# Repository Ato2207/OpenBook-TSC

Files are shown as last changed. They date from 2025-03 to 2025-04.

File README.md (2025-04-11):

# OpenBook-TSC

# 1. Diagrama bloc
Block Diagram OpenBook

# 2. Bill Of Materials (BOM)
| Nr. | Componentă | Cantitate | Link achiziție | Datasheet |
|----|---|---|---|---|
| 1  | ESP32-C6-WROOM-1-N8 | 1 | [Mouser](https://ro.mouser.com/ProductDetail/Espressif-Systems/ESP32-C6-WROOM-1-N8?qs=8Wlm6%252BaMh8ST02Gmwp74cw%3D%3D) | [Datasheet](https://ro.mouser.com/datasheet/2/891/Espressif_ESP32_C6_WROOM_1__Datasheet_V0_1_PRELIMI-3239987.pdf) |
| 2  | Regulator de tensiune 3.3V  | 1 | [Mouser](https://www.mouser.co.uk/ProductDetail/Torex-Semiconductor/XC6220A331MR-G?qs=AsjdqWjXhJ8ZSWznL1J0gg%3D%3D) | [Datasheet](https://www.mouser.co.uk/datasheet/2/760/xc6220-3371556.pdf) |
| 3  | Display | 1 | https://www.waveshare.com/7.5inch-e-paper-hat.htm | [Datasheet](https://files.waveshare.com/upload/6/60/7.5inch_e-Paper_V2_Specification.pdf) |
| 4  | Senzor BME688 | 1 | [Mouser](https://ro.mouser.com/ProductDetail/Bosch-Sensortec/BME688?qs=IS%252B4QmGtzzqQoVDscqwx3A%3D%3D)| [Datasheet](https://ro.mouser.com/datasheet/2/783/bst_bme688_fl000-2307034.pdf) |
| 5  | Baterie | 1 | [Mouser](https://www.tme.eu/ro/details/accu-lp584174_cl/acumulatori/cellevia-batteries/l584174/)| [Datasheet](https://www.tme.eu/Document/e0683d8c34e6d878124489f71bffb6ee/cel0014.pdf) |
| 6  | Fuel Gauge | 1 | [Mouser](https://ro.mouser.com/ProductDetail/Analog-Devices-Maxim-Integrated/MAX17048G%2bT10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) | [Datasheet](https://ro.mouser.com/datasheet/2/609/MAX17048_MAX17049-3469099.pdf) |
| 7  | Controller de incarcare | 1 | [Mouser](https://ro.mouser.com/ProductDetail/Microchip-Technology/MCP73831T-2ACI-MC?qs=yUQqVecv4quJ3ICqm%2FGZxw%3D%3D)| [Datasheet](https://ro.mouser.com/datasheet/2/268/MCP73831_Family_Data_Sheet_DS20001984H-3441711.pdf) |
| 8  | Butoane  | 3 | [Mouser](https://ro.mouser.com/ProductDetail/Panasonic/EVQ-Q2S03W?qs=WwqriLBepZso3gwmd6qd3A%3D%3D) | [Datasheet](https://4donline.ihs.com/images/VipMasterIC/IC/PANA/PANA-S-A0000770395/PANA-S-A0000770395-1.pdf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) |
| 9  | Conector USB-C  | 1 | [Mouser](https://ro.mouser.com/ProductDetail/Amphenol-Commercial-Products/12401598E42A?qs=367PjNmvCmllVMBVyIyS3w%3D%3D) | [Datasheet](https://cdn.amphenol-cs.com/media/wysiwyg/files/documentation/datasheet/inputoutput/io_usb_type_c.pdf) |
| 10  | Conector card SD  | 1 | [Mouser](https://www.digikey.ro/en/products/detail/attend-technology/112A-TAAR-R03/17633923) | [Datasheet](https://www.attend.com.tw/data/download/file/112A-TAAR-R03_Spec.pdf) |
| 11  | RTC DS3231  | 1 | [Mouser](https://www.optimusdigital.ro/en/others/12402-ds3231-real-time-clock-module.html) | [Datasheet](https://www.analog.com/media/en/technical-documentation/data-sheets/ds3231.pdf) |
| 12  | Memorie Flash 64MB externa  | 1 | [Mouser](https://ro.mouser.com/ProductDetail/Winbond/W25Q512JVEIQ?qs=l7cgNqFNU1jw6svr3at6tA%3D%3D) | [Datasheet](https://ro.mouser.com/datasheet/2/949/Winbond_W25Q512JV_Datasheet-3240039.pdf) |
| 13 | Tranzistoare  | 3 | - | - |
| 14 | Diode | 10 | - | - |
| 15 | Condensatori diversi  | 28 | - | - |
| 16  | Rezistente diverse | 24  | -  | - |

# 3. Functionalitate Hardware
  ## 3.1 Componente
  - **ESP32-C6-WROOM-1-N8** – Microcontroler principal care gestionează comunicațiile (SPI, I2C, UART) și controlează perifericele.  
  - **Conector USB-C & Protecție ESD** – Permite alimentarea prin USB-C și protejează circuitul de descărcările electrostatice.  
  - **Controler de Încărcare MCP73831** – Reglează încărcarea bateriei Li-Po și gestionează curentul de alimentare.  
  - **Baterie Li-Po** – Asigură alimentarea de rezervă pentru funcționare independentă de sursa USB.  
  - **Regulator de Tensiune LDO** – Stabilizează alimentarea la 3.3V pentru microcontroler și componente auxiliare.  
  - **Memorie Flash NOR Externă (64MB)** – Stocare suplimentară pentru date.
  - **Modul RTC DS3231SN** – Oferă funcționalitate de ceas în timp real, suportând alarme și detectarea pierderii tensiunii..  
  - **Senzor Ambiental BME688** – Măsoară temperatura, umiditatea, presiunea și calitatea aerului. Comunicare prin I2C, cu suport pentru conectare rapidă (Qwiic/Stemma QT).  
  - **E-Paper Display Drive Circuit si Header** – Genereaza semnalele necesare pentru controlul ecranului E-Paper.
  - **Slot SD Card** – Permite stocarea locală a datelor și fișierelor de configurare. 
  - **Supervizor de Tensiune + Butoane Reset/Boot** – Monitorizează alimentarea și asigură resetarea sistemului atunci când este necesar.

  ## 3.2 Specificatii de comunicare
  - **I2C** – Utilizat pentru senzorul BME688 și modulul DS3231SN.
  - **SPI** – Folosit pentru NOR Flash, display-ul E-Paper și cardul SD.
  - **UART** – Disponibil pentru debugging sau conectarea altor module. 
  - **Wi-Fi & Bluetooth LE** – Furnizate de ESP32-C6 pentru conectivitate wireless.

# 4. Pini ESP32-C6-WROOM-1-N8 si utilizare
| Pin ESP32-C6| Funcție | Modul de utilizare |
|---|---|---|
| **3V3** | Supply | Furnizează tensiune de 3.3V pentru componente. |
| **GND** | Ground | Referință pentru circuit. |
| **EN** | Enable | Permite pornirea/resetarea modulului (tensiune ridicată = activ). |
| **IO0** | Interrupt | Pentru notificari, conectat la modulul RTC. |
| **IO1** | RTC CLK | Semnal de ceas pentru modulul RTC. |
| **IO2** | SPI MISO | Primire date de la periferice conectate prin SPI. |
| **IO3** | Status | Semnalizeaza starea de ocupay a display-ului. |
| **IO4** | Slave Select | Selecteaza cardul SD. |
| **IO5** | Data/Command | Selecteaza intre modul de date si comenzi. |
| **IO6** | SPI CLK | Semnal de ceas pentru SPI. |
| **IO7** | SPI MOSI | Transfer date catre periferice conectate prin SPI. |
| **IO8** | GPIO | Pin general GPIO. |
| **IO9** | Boot | Conectat la un buton pentru intrarea in modul de boot. |
| **IO10** | Chip Select | Activeaza comunicarea cu display-ul. |
| **IO11** | Chip Select | Activeaza comunicarea cu memoria flash. | 
| **IO12** | USB_D- | Pentru USB. |
| **IO13** | USB_D+ | Pentru USB. |
| **IO15** | Change | Conectat la un buton. |
| **IO16** | TX | Pentru UART. |
| **IO17** | RX | Pentru UART. |
| **IO18** | RTC_RST | Pentru resetarea modulului RTC. |
| **IO19** | I2C_PW | Supply pentru I2C. |
| **IO20** | EPD_3V3_C | Alimentare display. |
| **IO21** | SDA | Linia de date pentru I2C. |
| **IO22** | SCL | Semnalul de ceas pentru I2C. |
| **IO23** | EPD_RST | Pentru resetarea display-ului. |

# 4. Implementare

## 4.1 Documentatie
Am inceput prin a citi documentele puse la dispozitie, in ordinea data: MRD, PRD, ERD si documentul de Detailed Design si am extras anumite informatii utile referitoare la modul de functionare al device-ului.

## 4.2 Schematic
In continuare, prin comparare, am realizat schema electrica precum a fost data in cerinta, respectand toate constrangerile.Ulterior am facut si verificarea ERC si am rezolvat toate erorile semnalate, cu exceptia celor mentionate ca fiind acceptabile.

## 4.3 PCB
Dupa realizarea schemei electrice, am trecut la partea de board design, pastrand dimensiunile recomandate.Am amplasat componenetele exclusiv pe layer-ul TOP, respectand cu strictete pozitia celor care au contact cu exteriorul.Am realizat doua plane de masa(TOP & BOTTOM) si am aplicat via stitching, in special in jurul modulului ESP32.Am urmat constrangerile de rutare(DRC), inclusiv decuparea PCB-ului sub antena ESP32-ului pentru a nu ruta semnale in acea zona.In final, am realizat silkscreen-ul si am marcat toate test pad-urile cu numele semnalelor.

## 4.4 3D
Am importat carcasa data si am realizat modelul 3D al bateriei si al ecranului, desenate pe baza dimensiunilor din datasheet-uri.Avand toate piesele, le-am asezat in carcasa corespunzator pentru a nu avea suprapuneri si am aliniat PCB-ul cu mufa USB si slot-ul SD.

# 5. Dificultati intalnite si decizii luate

## Lipsa modele 3D
Pentru anumite componente nu am reusit sa gasesc chiar modelul 3D perfect, spre exemplu la butoane, card SD, connector-ul QWIIC, asa ca am ales sa merg pe ceva apropiat.

## Erori
Footprint-ul mufei USB are 2 erori de "Smd-Hole, Board Outline Clearance" cauzate de faptul ca gaurile de sustinere a componentei sunt prea apropiate de pini, conform fisierului de constrangeri.Astfel, am decis sa le aprob deoarece nu depindeau de mine.

## Vias-uri
Am incercat pe cat posibil sa evit folosirea vias-urilor la traseele de putere si aproape am reusit in totalitate, avand nevoie doar de unul singur la semnalul de VBAT.

## Display
Am realizat display-ul conform dimensiunilor din datasheet, dar acesta nu se potrivea in carcasa, asa ca am fost nevoit sa il fac independent de acele valori.

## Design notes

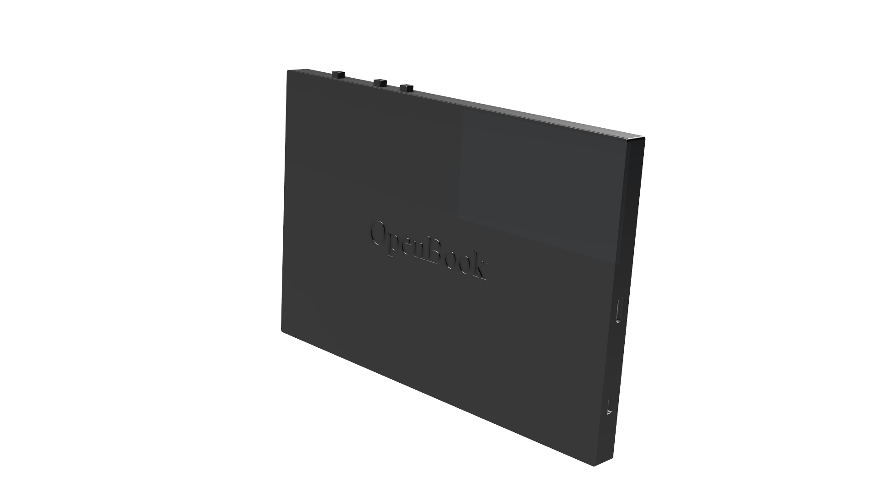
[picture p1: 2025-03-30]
Images/Full device 1.png

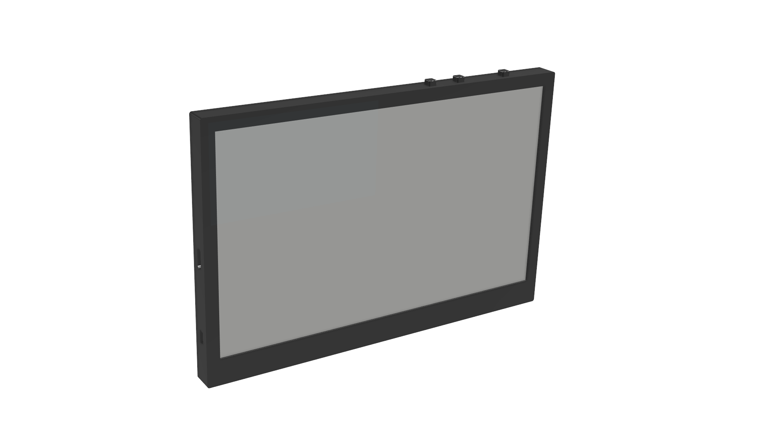
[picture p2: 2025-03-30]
Images/Full device 2.png

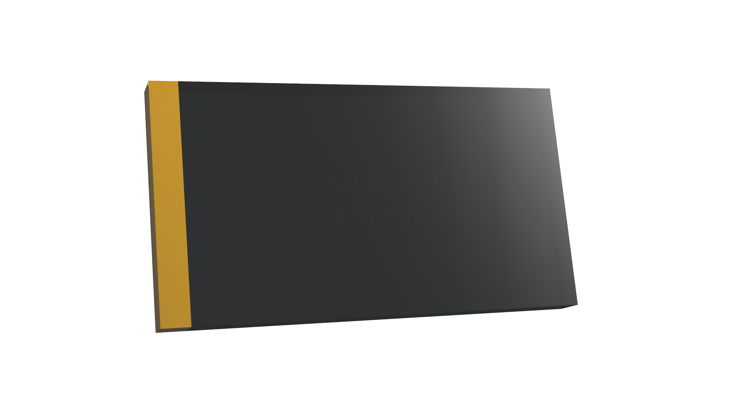
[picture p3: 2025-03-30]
Images/Battery.png

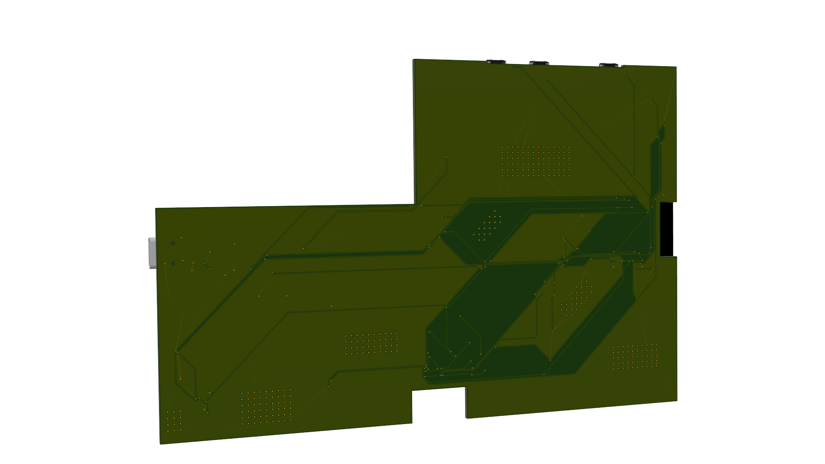
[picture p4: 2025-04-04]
Images/PCB 2.png

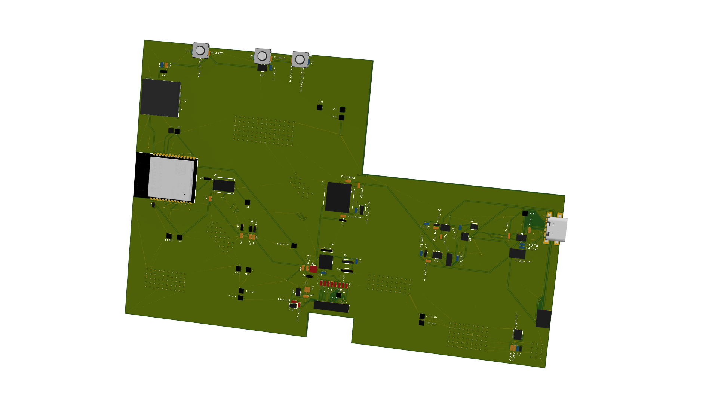
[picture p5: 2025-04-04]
Images/PCB 1.png

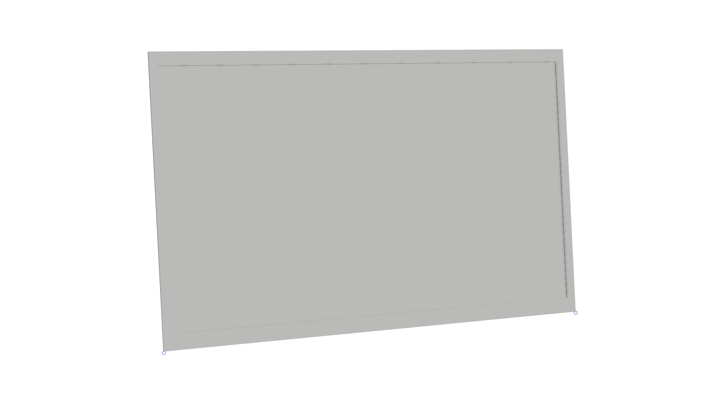
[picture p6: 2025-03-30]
Images/Display.png

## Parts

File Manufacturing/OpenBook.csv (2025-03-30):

Qty | Value | Device | Package | Parts | Description | ARROW_PART_NUMBER | ARROW_PRICE-STOCK | AVAILABILITY | CENTROID_NOT_SPECIFIED | CHECK_PRICES | COMP_NAME | COPYRIGHT | DATASHEET | DESCRIPTION | DIGIKEY_DESCRIPTION | DIGIKEY_PART_NUMBER | HEIGHT | LEAD_FREE | MANUFACTURER_NAME | MANUFACTURER_PART_NUMBER | MF | MFR_NAME | MOUSER_PART_NUMBER | MOUSER_PRICE-STOCK | MOUSER_TESTING_PART_NUMBER | MOUSER_TESTING_PRICE-STOCK | MP | MPN | NEW_MP | PACKAGE | POPULARITY | PREFIX | PRICE | PROD_ID | PURCHASE-URL | ROHS | SNAPEDA_LINK | SPICEMODEL | SPICEPREFIX | TEMPERATURE_RANGE_HIGH | TEMPERATURE_RANGE_LOW | TP_SIGNAL_NAME | VALUE | VALUE_COPY
1 | - | ADAFRUIT_LEDCHIP-LED0603 | ADAFRUIT_CHIP-LED0603 | CHG_LED | LED
1 | - | SJ | SJ | SJ1 | SMD solder JUMPER |  |  |  |  |  |  |  |  |  |  |  |  |  |  |  |  |  |  |  |  |  |  |  |  |  | 3
1 | 0.1uF/50V | EAGLE-LTSPICE_CC0402 | EAGLE-LTSPICE_C0402 | EPD_C5 | CAPACITOR, European symbol |  |  |  |  |  |  |  |  |  |  |  |  |  |  |  |  |  |  |  |  |  |  |  |  |  |  |  |  |  |  |  |  | NONE | C
1 | 0.47 | ESP32_WROVER_EAGLE-LTSPICE_RR0402 | ESP32_WROVER_EAGLE-LTSPICE_R0402 | R3 | RESISTOR, European symbol |  |  |  |  |  |  |  |  |  |  |  |  |  |  |  |  |  |  |  |  |  |  |  |  |  |  |  |  |  |  |  |  | NONE | R
1 | 100K | ESP32_WROVER_EAGLE-LTSPICE_RR0402 | ESP32_WROVER_EAGLE-LTSPICE_R0402 | R1_PWRUSB | RESISTOR, European symbol |  |  |  |  |  |  |  |  |  |  |  |  |  |  |  |  |  |  |  |  |  |  |  |  |  |  |  |  |  |  |  |  | NONE | R
8 | 100nF | EAGLE-LTSPICE_CC0402 | EAGLE-LTSPICE_C0402 | C1, C2, C4_USB, C6, C8, C9, C10, C_DELAY | CAPACITOR, European symbol |  |  |  |  |  |  |  |  |  |  |  |  |  |  |  |  |  |  |  |  |  |  |  |  |  |  |  |  |  |  |  |  | NONE | C
1 | 100uF TANT | RCL_CPOL-EUCT3528 | RCL_CT3528 | C3 | POLARIZED CAPACITOR, European symbol |  |  |  |  |  |  |  |  |  |  |  |  |  |  |  |  |  |  |  |  |  |  |  |  |  | 0 |  |  |  |  |  |  |  | C
16 | 10K | ESP32_WROVER_EAGLE-LTSPICE_RR0402 | ESP32_WROVER_EAGLE-LTSPICE_R0402 | R1, R1_PINH, R1_PINH1, R2-PINH1, R2_PINH, R4, R5, R6, R7, R8, R9, R10, R_BOOT, R_CHANGE, R_CL1, R_RESET | RESISTOR, European symbol |  |  |  |  |  |  |  |  |  |  |  |  |  |  |  |  |  |  |  |  |  |  |  |  |  |  |  |  |  |  |  |  | NONE | R
1 | 10uF | EAGLE-LTSPICE_CC0402 | EAGLE-LTSPICE_C0402 | C7 | CAPACITOR, European symbol |  |  |  |  |  |  |  |  |  |  |  |  |  |  |  |  |  |  |  |  |  |  |  |  |  |  |  |  |  |  |  |  | NONE | C
1 | 112A-TAAR-R03_ATTEND | 112A-TAAR-R03_ATTEND | 112ATAARR03ATTEND | J4 | Micro SD Card Socket, Push-Push Type, Top Mount, SMT, H=1.83mm, 10u |  |  |  |  |  |  |  |  | Micro SD Card Socket | Push-Push Type | Top Mount | SMT | H=1.83mm | 10u |  |  | 1.9mm |  | ATTEND | 112A-TAAR-R03 ATTEND
1 | 15 | ESP32_WROVER_EAGLE-LTSPICE_RR0402 | ESP32_WROVER_EAGLE-LTSPICE_R0402 | R_CAPACITOR | RESISTOR, European symbol |  |  |  |  |  |  |  |  |  |  |  |  |  |  |  |  |  |  |  |  |  |  |  |  |  |  |  |  |  |  |  |  | NONE | R
1 | 1uF | EAGLE-LTSPICE_CC0402 | EAGLE-LTSPICE_C0402 | C5 | CAPACITOR, European symbol |  |  |  |  |  |  |  |  |  |  |  |  |  |  |  |  |  |  |  |  |  |  |  |  |  |  |  |  |  |  |  |  | NONE | C
9 | 1uF/50V | EAGLE-LTSPICE_CC0402 | EAGLE-LTSPICE_C0402 | EPD_C1, EPD_C2, EPD_C6, EPD_C7, EPD_C8, EPD_C9, EPD_C10, EPD_C11, EPD_C12 | CAPACITOR, European symbol |  |  |  |  |  |  |  |  |  |  |  |  |  |  |  |  |  |  |  |  |  |  |  |  |  |  |  |  |  |  |  |  | NONE | C
1 | 2.2 | ESP32_WROVER_EAGLE-LTSPICE_RR0402 | ESP32_WROVER_EAGLE-LTSPICE_R0402 | R2 | RESISTOR, European symbol |  |  |  |  |  |  |  |  |  |  |  |  |  |  |  |  |  |  |  |  |  |  |  |  |  |  |  |  |  |  |  |  | NONE | R
1 | 200 | ESP32_WROVER_EAGLE-LTSPICE_RR0402 | ESP32_WROVER_EAGLE-LTSPICE_R0402 | R1_BAT | RESISTOR, European symbol |  |  |  |  |  |  |  |  |  |  |  |  |  |  |  |  |  |  |  |  |  |  |  |  |  |  |  |  |  |  |  |  | NONE | R
1 | 20V/4.2A/52mO/1.4W | ESP32_WROVER_SPARKFUN-DISCRETESEMI_MOSFET_PCH-DMG2305UX-7 | ESP32_WROVER_SPARKFUN-DISCRETESEMI_SOT23-3 | Q2 | P-channel MOSFETs |  |  |  |  |  |  |  |  |  |  |  |  |  |  |  |  |  |  |  |  |  | DMG2305UX-7 |  |  |  |  |  |  | TRAN-14388 |  |  |  |  |  |  |  |  | 20V/4.2A/52mO/1.4W
1 | 20V/4.2A/52mO/1.4W | ESP32_WROVER_SPARKFUN-DISCRETESEMI_MOSFET_PCH-DMG2305UX-7 | ESP32_WROVER_SPARKFUN-DISCRETESEMI_SOT23-3 | Q1 | P-channel MOSFETs |  |  |  |  |  | DMG2305UX-7 |  |  |  |  |  |  |  |  |  |  |  |  |  |  |  |  |  |  |  |  |  |  | TRAN-14388 |  |  |  |  |  |  |  |  | 20V/4.2A/52mO/1.4W
1 | 2K | ESP32_WROVER_EAGLE-LTSPICE_RR0402 | ESP32_WROVER_EAGLE-LTSPICE_R0402 | R2_BAT | RESISTOR, European symbol |  |  |  |  |  |  |  |  |  |  |  |  |  |  |  |  |  |  |  |  |  |  |  |  |  |  |  |  |  |  |  |  | NONE | R
5 | 4.7uF | EAGLE-LTSPICE_CC0402 | EAGLE-LTSPICE_C0402 | C1_BAT, C1_BAT1, C1_BAT2, C2_BAT, C5_USB | CAPACITOR, European symbol |  |  |  |  |  |  |  |  |  |  |  |  |  |  |  |  |  |  |  |  |  |  |  |  |  |  |  |  |  |  |  |  | NONE | C
1 | 4.7uF/25V | EAGLE-LTSPICE_CC0402 | EAGLE-LTSPICE_C0402 | C4 | CAPACITOR, European symbol |  |  |  |  |  |  |  |  |  |  |  |  |  |  |  |  |  |  |  |  |  |  |  |  |  |  |  |  |  |  |  |  | NONE | C
2 | 5k1 | ESP32_WROVER_EAGLE-LTSPICE_RR0402 | ESP32_WROVER_EAGLE-LTSPICE_R0402 | R2-USB, R2-USB1 | RESISTOR, European symbol |  |  |  |  |  |  |  |  |  |  |  |  |  |  |  |  |  |  |  |  |  |  |  |  |  |  |  |  |  |  |  |  | NONE | R
1 | 68uH | 744043680IND_4828-WE-TPC_WRE | IND_4828-WE-TPC_WRE | L1 |  |  |  |  |  |  |  | Copyright (C) 2024 Ultra Librarian. All rights reserved. |  |  |  |  |  |  |  | 744043680 |  | Wurth Electronics
1 | BD5229G-TR | BD5229G-TR | SOT95P280X125-5N | IC1 | Voltage Detector with Adjustable Delay Time: CMOS processes are utilized to develop high precision, low current consumption CMOS reset ICs that allow arbitrary setting of the delay time. The extensive lineup includes both Nch Open Drain and CMOS output types in a wide range of detection voltages (from 2.3V to 6.0V, in 0.1V steps), enabling selection of the ideal solution based on customer requirements. In addition, the entire series is of course both lead-free and RoHS-compliant. |  |  |  |  |  |  |  |  | Voltage Detector with Adjustable Delay Time: CMOS processes are utilized to develop high precision | low current consumption CMOS reset ICs that allow arbitrary setting of the delay time. The extensive lineup includes both Nch Open Drain and CMOS output types in a wide range of detection voltages (from 2.3V to 6.0V | in 0.1V steps) | enabling selection of the ideal solution based on customer requirements. In addition | the entire series is of course both lead-free and RoHS-compliant. |  |  | 1.25mm |  | ROHM Semiconductor | BD5229G-TR |  |  | 755-BD5229G-TR | https://www.mouser.co.uk/ProductDetail/ROHM-Semiconductor/BD5229G-TR?qs=4kLU8WoGk0vvnhrrYwdszw%3D%3D
3 | BUTTON_CUSYOMV1 | BUTTON_CUSYOMV1 | MYBUTTON | BOOT_BUTTON, CHANGE_BUTTON, RESET_BUTTON
1 | CPH3225A | CPH3225A | CAPCP3225X100N | C10_SUPERCAP | Cap 0.011F 3.3V 1210 Flat Check availability |  |  | Not in stock |  | https://www.snapeda.com/parts/CPH3225A/Seiko+Instruments/view-part/?ref=eda |  |  |  | 11 mF (EDLC) Supercapacitor 3.3 V 1210 (3225 Metric) - - |  |  |  |  |  |  | Seiko Instruments |  |  |  |  |  | CPH3225A |  |  | 1210 Seiko |  |  | None |  | https://www.snapeda.com/api/url_track_click_mouser/?unipart_id=562593&manufacturer=Seiko Instruments&part_name=CPH3225A&search_term=None |  | https://www.snapeda.com/parts/CPH3225A/Seiko+Instruments/view-part/?ref=snap
1 | DS3231SN# | DS3231SN# | SOIC127P1032X265-16N | U3 | Real Time Clock Serial 16-Pin SOIC W T/R Check availability |  |  | In Stock |  | https://www.snapeda.com/parts/DS3231SN%23/Analog+Devices/view-part/?ref=eda |  |  |  | Extremely Accurate I²C-Integrated RTC/TCXO/Crystal |  |  |  |  |  |  | Analog Devices |  |  |  |  |  | DS3231SN# |  |  | SOIC-16 Maxim |  |  | None |  | https://www.snapeda.com/api/url_track_click_mouser/?unipart_id=99048&manufacturer=Analog Devices&part_name=DS3231SN#&search_term=None |  | https://www.snapeda.com/parts/DS3231SN%23/Analog+Devices/view-part/?ref=snap
1 | ESP32-C6-WROOM-1-N8 | ESP32-C6-WROOM-1-N8 | XCVR_ESP32-C6-WROOM-1-N8 | U2 | Check availability |  |  | In Stock |  | https://www.snapeda.com/parts/ESP32-C6-WROOM-1-N8/Espressif+Systems/view-part/?ref=eda |  |  |  | Multiprotocol Modules ESP32-C6 module | Wi-Fi 6 in 2.4 GHz band | Bluetooth 5 | Zigbee 3.0 and Thread. ESP34-WROOM Compatible - ENGINEERING SAMPLE |  |  |  |  |  |  | Espressif Systems |  |  |  |  |  | ESP32-C6-WROOM-1-N8 |  |  | None |  |  | None |  |  |  | https://www.snapeda.com/parts/ESP32-C6-WROOM-1-N8/Espressif+Systems/view-part/?ref=snap
1 | ESP32C6_VARISTORCN1812 | ESP32C6_VARISTORCN1812 | ESP32C6_VARISTOR_CT/CN1812 | PFMF.050.1 | VARISTOR |  |  |  |  |  |  |  |  |  |  |  |  |  |  |  |  |  |  |  |  |  |  |  |  |  | 0
1 | ESP32_WROVER_AVX---SD0805S020S1R0_AVX_SD0805S020S1R0_0_0AVX_SD0805S020S1R0_0_0 | ESP32_WROVER_AVX---SD0805S020S1R0_AVX_SD0805S020S1R0_0_0AVX_SD0805S020S1R0_0_0 | ESP32_WROVER_AVX---SD0805S020S1R0_AVX_SD0805S020S1R0_0 | D7 | Schottky Barrier Rectifier Diode |  |  |  | No |  |  |  | http://datasheets.avx.com/schottky.pdf |  | DIODE SCHOTTKY 20V 1A 0805 | 478-7800-1-ND |  | yes |  |  | AVX |  | 581-SD0805S020S1R0 |  |  |  |  |  |  | 0805 (2012 metric) |  | D |  |  |  | yes |  |  |  | +125°C | -55°C |  |  | SD0805S020S1R0
1 | ESP32_WROVER_BME680_BME680 | ESP32_WROVER_BME680_BME680 | ESP32_WROVER_BME680_PSON80P300X300X100-8N | SENSOR2 | Integrated Environmental Unit |  |  | Unavailable |  |  |  |  |  | Integrated Environmental Unit |  |  |  |  |  |  | Bosch Sensortec |  |  |  |  |  | BME680 |  | BME688 | LGA-8 Bosch Tools |  |  | None
1 | FH34SRJ-24S-0.5SH_99_ | FH34SRJ-24S-0.5SH_99_ | FH34SRJ24S05SH99 | J1 | (0.50mm) Surface Mount, Right Angle |  |  |  |  |  |  |  |  | 24 Position FFC | FPC Connector Contacts | (0.50mm) Surface Mount | Right Angle |  |  | 1.1mm |  | Hirose | FH34SRJ-24S-0.5SH(99) |  |  | 798-FH34SRJ24S05SH99 | https://www.mouser.co.uk/ProductDetail/Hirose-Connector/FH34SRJ-24S-0.5SH99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
1 | MAX17048G+T10 | MAX17048G+T10 | SON50P200X200X80-9N | U4 | Check availability |  |  | In Stock |  | https://www.snapeda.com/parts/MAX17048G+T10/Analog+Devices/view-part/?ref=eda |  |  |  | 3µA 1-Cell/2-Cell Fuel Gauge with ModelGauge |  |  |  |  |  |  | Analog Devices |  |  |  |  |  | MAX17048G+T10 |  |  | TDFN-8 Maxim |  |  | None |  | https://www.snapeda.com/api/url_track_click_mouser/?unipart_id=329239&manufacturer=Analog Devices&part_name=MAX17048G+T10&search_term=None |  | https://www.snapeda.com/parts/MAX17048G+T10/Analog+Devices/view-part/?ref=snap
3 | MBR0530 | MBR0530 | SOD3716X135N | D3, D4, D5 | ON SEMICONDUCTOR - MBR0530 - DIODE, SCHOTTKY, 0.5A, 30V, SOD-123 |  |  | In Stock |  | https://www.snapeda.com/parts/MBR0530/Onsemi/view-part/?ref=eda |  |  |  | Diode Schottky 30 V 500mA Surface Mount SOD-123 |  |  |  |  |  |  | ON Semiconductor |  |  |  |  |  | MBR0530 |  |  | SOD-123-2 ON Semiconductor |  |  | None |  | https://www.snapeda.com/api/url_track_click_mouser/?unipart_id=179458&manufacturer=ON Semiconductor&part_name=MBR0530&search_term=None |  | https://www.snapeda.com/parts/MBR0530/Onsemi/view-part/?ref=snap
1 | MCP73831 | ESP32_WROVER_SPARKFUN-IC-POWER_MCP73831 | ESP32_WROVER_SPARKFUN-IC-POWER_SOT23-5 | U5 | MCP73831T Li-Ion, Li-Pol Controller |  |  |  |  |  |  |  |  |  |  |  |  |  |  |  |  |  |  |  |  |  |  |  |  |  |  |  |  | IC-09995
6 | PGB1010603MR | PGB1010603MR | DIOC1608X36N | D6, D8, D9, D10, D11, D12 | Check availability |  |  | In Stock |  | https://www.snapeda.com/parts/PGB1010603MR/Littelfuse/view-part/?ref=eda |  |  |  | 150V (Typ) Clamp - Ipp Tvs Diode Surface Mount 0603 (1608 Metric) |  |  |  |  |  |  | Littelfuse Inc. |  |  |  |  |  | PGB1010603MR |  |  | 0603 Littelfuse Inc. |  |  | None |  | https://www.snapeda.com/api/url_track_click_mouser/?unipart_id=5659453&manufacturer=Littelfuse Inc.&part_name=PGB1010603MR&search_term=None |  | https://www.snapeda.com/parts/PGB1010603MR/Littelfuse/view-part/?ref=snap
1 | QWIIC_RIGHT_ANGLE | QWIIC_CONNECTORJS-1MM | JST04_1MM_RA | J3 | SparkFun I2C Standard Qwiic Connector |  |  |  |  |  |  |  |  |  |  |  |  |  |  |  |  |  |  |  |  |  |  |  |  |  |  |  |  | CONN-13694 |  |  |  |  |  |  |  |  | QWIIC_RIGHT_ANGLE
1 | SAMACSYS_PARTS_USB4110-GF-A | SAMACSYS_PARTS_USB4110-GF-A | SAMACSYS_PARTS_USB4110GFA | J2 | CONN USB 2.0 TYPE-C R/A SMT |  |  |  |  |  |  |  |  | CONN USB 2.0 TYPE-C R/A SMT |  |  | 3.26mm |  | GCT (GLOBAL CONNECTOR TECHNOLOGY) | USB4110-GF-A |  |  | 640-USB4110-GF-A | https://www.mouser.co.uk/ProductDetail/GCT/USB4110-GF-A?qs=KUoIvG%2F9IlYiZvIXQjyJeA%3D%3D
1 | SD0805S020S1R0 | ESP32_WROVER_AVX---SD0805S020S1R0_AVX_SD0805S020S1R0_0_0AVX_SD0805S020S1R0_0_0 | ESP32_WROVER_AVX---SD0805S020S1R0_AVX_SD0805S020S1R0_0 | D2 | Schottky Barrier Rectifier Diode |  |  |  | No |  |  |  | http://datasheets.avx.com/schottky.pdf |  | DIODE SCHOTTKY 20V 1A 0805 | 478-7800-1-ND |  | yes |  |  | AVX |  | 581-SD0805S020S1R0 |  |  |  |  |  |  | 0805 (2012 metric) |  | D |  |  |  | yes |  |  |  | +125°C | -55°C |  |  | SD0805S020S1R0
1 | SI1308EDL-T1-GE3 | SI1308EDL-T1-GE3 | SOT65P210X110-3N | Q3 | MOSFET N-Ch 30V 1.5A TrenchFET SC70 Vishay Si1308EDL-T1-GE3 N-channel MOSFET Transistor, 1.5 A, 30 V, 3-Pin SC-70 |  |  | In Stock |  | https://www.snapeda.com/parts/SI1308EDL-T1-GE3/Vishay+Siliconix/view-part/?ref=eda |  |  |  | Si1308EDL-T1-GE3 N-channel MOSFET Transistor | 1.5 A | 30 V | 3-Pin SC-70 | Siliconix / Vishay SI1308EDL-T1-GE3 |  |  |  |  |  |  | Vishay Siliconix |  |  |  |  |  | SI1308EDL-T1-GE3 |  |  | SOT-323 Vishay Semiconductor |  |  | None |  | https://www.snapeda.com/api/url_track_click_mouser/?unipart_id=274603&manufacturer=Vishay Siliconix&part_name=SI1308EDL-T1-GE3&search_term=None |  | https://www.snapeda.com/parts/SI1308EDL-T1-GE3/Vishay+Siliconix/view-part/?ref=snap
17 | TPTP20R | TPTP20R | TP20R | TP1, TP2, TP3, TP4, TP5, TP6, TP7, TP8, TP9, TP10, TP11, TP12, TP13, TP14, TP15, TP16, TP17 | Test pad |  |  |  |  |  |  |  |  |  |  |  |  |  |  |  |  |  |  |  |  |  |  |  |  |  | 2
1 | USBLC6-2SC6Y | USBLC6-2SC6Y | SOT95P280X145-6N | D1 | Low Cap. ESD Protection Auto SOT-23-6 STMicroelectronics USBLC6-2SC6Y, Dual Uni-Directional TVS Diode Array, 6-Pin SOT-23 |  |  | In Stock |  | https://www.snapeda.com/parts/USBLC6-2SC6Y/STMicroelectronics/view-part/?ref=eda |  |  |  | 17V Clamp 5A (8/20µs) Ipp Tvs Diode Surface Mount SOT-23-6 |  |  |  |  |  |  | STMicroelectronics |  |  |  |  |  | USBLC6-2SC6Y |  |  | SOT-23-6 STMicroelectronics |  |  | None |  |  |  | https://www.snapeda.com/parts/USBLC6-2SC6Y/STMicroelectronics/view-part/?ref=snap
1 | W25Q512JVEIQ | W25Q512JVEIQ | SON127P600X800X80-9N | U1 | Check availability |  |  | In Stock |  | https://www.snapeda.com/parts/W25Q512JVEIQ/Winbond+Electronics/view-part/?ref=eda |  |  |  | FLASH - NOR Memory IC 512Mb (64M x 8) SPI - Quad I/O 133 MHz 8-WSON (8x6) |  |  |  |  |  |  | Winbond Electronics |  |  |  |  |  | W25Q512JVEIQ |  |  | Package |  |  | None |  |  |  | https://www.snapeda.com/parts/W25Q512JVEIQ/Winbond+Electronics/view-part/?ref=snap
1 | XC6220A331MR-G | XC6220A331MR-G | SOT95P280X120-5N | IC4 | LDO Voltage Regulators |  |  |  |  |  |  |  |  | LDO Voltage Regulators |  |  | 1.2mm |  | Torex | XC6220A331MR-G |  |  | 865-XC6220A331MR-G | https://www.mouser.co.uk/ProductDetail/Torex-Semiconductor/XC6220A331MR-G?qs=AsjdqWjXhJ8ZSWznL1J0gg%3D%3D

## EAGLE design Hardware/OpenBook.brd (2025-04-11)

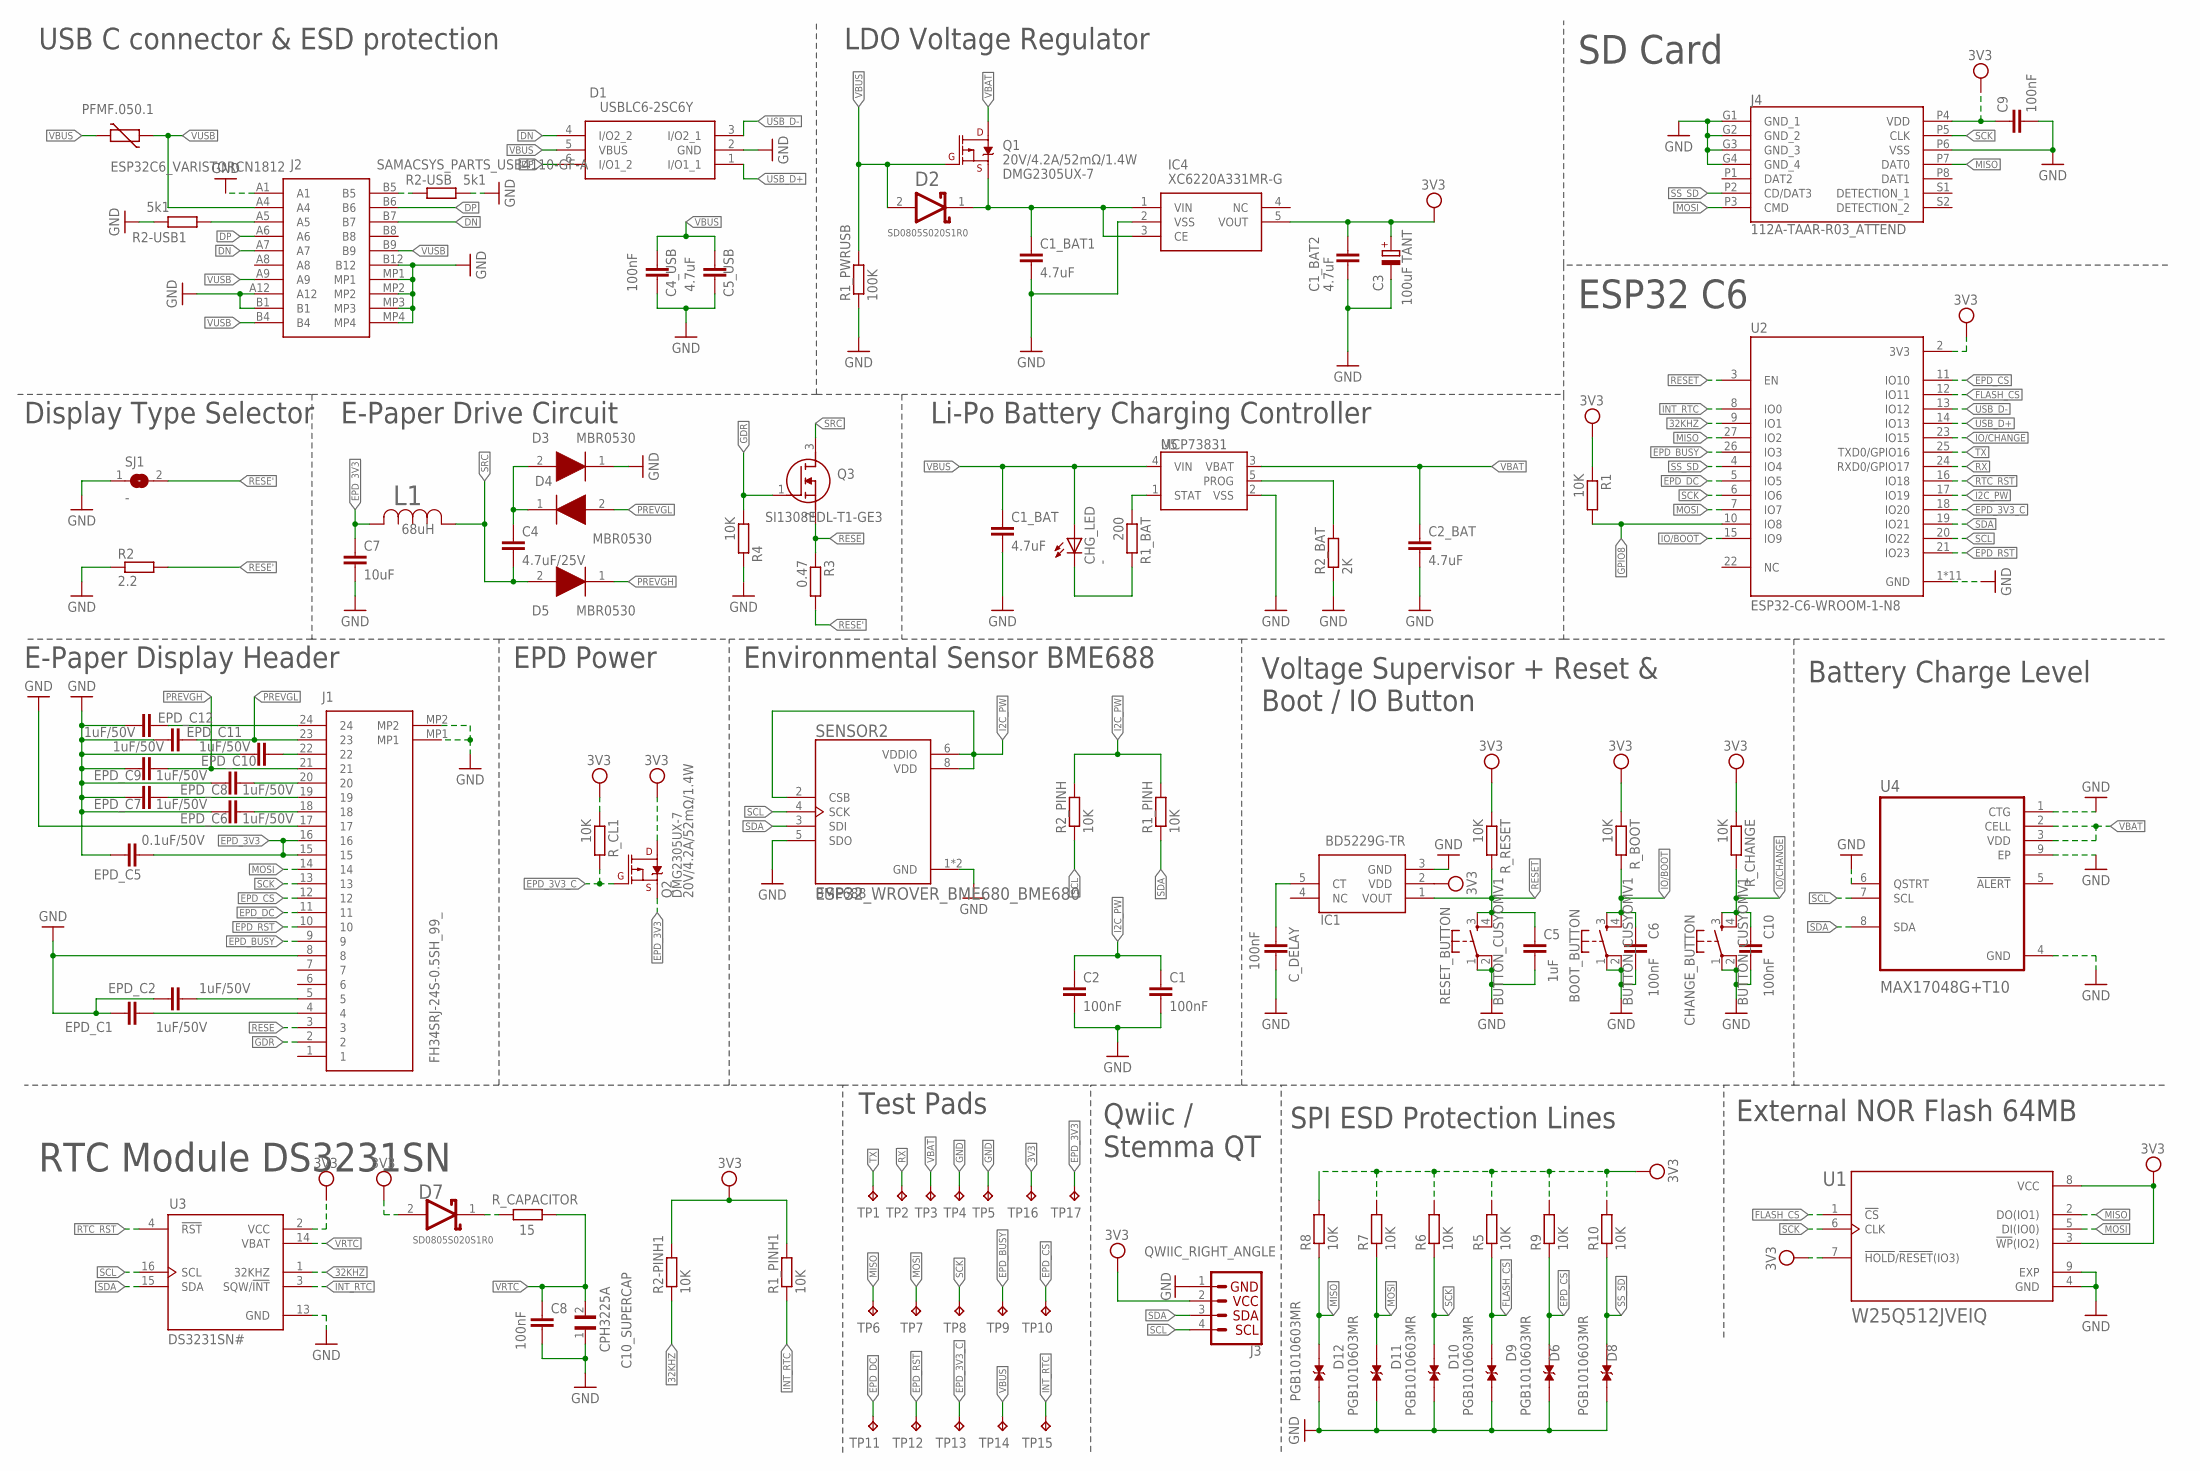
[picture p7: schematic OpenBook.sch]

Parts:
BOOT_BUTTON: BUTTON_CUSYOMV1; MYBUTTON
C1, C2, C4_USB, C6, C8, C9, C10: 100nF; EAGLE-LTSPICE_C0402
C1_BAT, C1_BAT1, C1_BAT2, C2_BAT, C5_USB: 4.7uF; EAGLE-LTSPICE_C0402
C3: 100uF TANT; RCL_CT3528
C4: 4.7uF/25V; EAGLE-LTSPICE_C0402
C5: 1uF; EAGLE-LTSPICE_C0402
C7: 10uF; EAGLE-LTSPICE_C0402
C10_SUPERCAP: CPH3225A; CAPCP3225X100N
CHANGE_BUTTON: BUTTON_CUSYOMV1; MYBUTTON
CHG_LED: -; ADAFRUIT_CHIP-LED0603
C_DELAY: 100nF; EAGLE-LTSPICE_C0402
D1: USBLC6-2SC6Y; SOT95P280X145-6N
D2: SD0805S020S1R0; ESP32_WROVER_AVX---SD0805S020S1R0_AVX_SD0805S020S1R0_0
D3, D4, D5: MBR0530; SOD3716X135N
D6, D8, D9, D10, D11, D12: PGB1010603MR; DIOC1608X36N
D7: ESP32_WROVER_AVX---SD0805S020S1R0_AVX_SD0805S020S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; ESP32_WROVER_AVX---SD0805S020S1R0_AVX_SD0805S020S1R0_0
EPD_C1, EPD_C2, EPD_C6, EPD_C7, EPD_C8, EPD_C9, EPD_C10, EPD_C11, EPD_C12: 1uF/50V; EAGLE-LTSPICE_C0402
EPD_C5: 0.1uF/50V; EAGLE-LTSPICE_C0402
IC1: BD5229G-TR; SOT95P280X125-5N
IC4: XC6220A331MR-G; SOT95P280X120-5N
J1: FH34SRJ-24S-0.5SH_99_; FH34SRJ24S05SH99
J2: SAMACSYS_PARTS_USB4110-GF-A; SAMACSYS_PARTS_USB4110GFA
J3: QWIIC_RIGHT_ANGLE; JST04_1MM_RA
J4: 112A-TAAR-R03_ATTEND; 112ATAARR03ATTEND
L1: 68uH; IND_4828-WE-TPC_WRE
PFMF.050.1: ESP32C6_VARISTORCN1812; ESP32C6_VARISTOR_CT/CN1812
Q1, Q2: 20V/4.2A/52mΩ/1.4W; ESP32_WROVER_SPARKFUN-DISCRETESEMI_SOT23-3
Q3: SI1308EDL-T1-GE3; SOT65P210X110-3N
R1, R1_PINH, R1_PINH1, R2-PINH1, R2_PINH, R4, R5, R6, R7, R8, R9, R10: 10K; ESP32_WROVER_EAGLE-LTSPICE_R0402
R1_BAT: 200; ESP32_WROVER_EAGLE-LTSPICE_R0402
R1_PWRUSB: 100K; ESP32_WROVER_EAGLE-LTSPICE_R0402
R2: 2.2; ESP32_WROVER_EAGLE-LTSPICE_R0402
R2-USB, R2-USB1: 5k1; ESP32_WROVER_EAGLE-LTSPICE_R0402
R2_BAT: 2K; ESP32_WROVER_EAGLE-LTSPICE_R0402
R3: 0.47; ESP32_WROVER_EAGLE-LTSPICE_R0402
RESET_BUTTON: BUTTON_CUSYOMV1; MYBUTTON
R_BOOT: 10K; ESP32_WROVER_EAGLE-LTSPICE_R0402
R_CAPACITOR: 15; ESP32_WROVER_EAGLE-LTSPICE_R0402
R_CHANGE: 10K; ESP32_WROVER_EAGLE-LTSPICE_R0402
R_CL1: 10K; ESP32_WROVER_EAGLE-LTSPICE_R0402
R_RESET: 10K; ESP32_WROVER_EAGLE-LTSPICE_R0402
SENSOR2: ESP32_WROVER_BME680_BME680; ESP32_WROVER_BME680_PSON80P300X300X100-8N
SJ1: -; SJ
TP1, TP2, TP3, TP4, TP5, TP6, TP7, TP8, TP9, TP10, TP11, TP12, TP13, TP14, TP15, TP16, TP17: TPTP20R; TP20R
U1: W25Q512JVEIQ; SON127P600X800X80-9N
U2: ESP32-C6-WROOM-1-N8; XCVR_ESP32-C6-WROOM-1-N8
U3: DS3231SN#; SOIC127P1032X265-16N
U4: MAX17048G+T10; SON50P200X200X80-9N
U5: MCP73831; ESP32_WROVER_SPARKFUN-IC-POWER_SOT23-5

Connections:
3V3: C1_BAT2.1, C3.+, C9.1, D7.2 (ANODE), IC1.2 (VDD), IC4.5 (VOUT), J3.2, J4.P4 (VDD), Q2.3 (D), R1.1, R1_PINH1.2, R2-PINH1.2, R5.2, R6.2, R7.2, R8.2, R9.2, R10.2, R_BOOT.1, R_CHANGE.1, R_CL1.1, R_RESET.1, TP16.TP, U1.3 (!WP!(IO2)), U1.7 (!HOLD!/!RESET!(IO3)), U1.8 (VCC), U2.2 (3V3), U3.2 (VCC)
32KHZ: R2-PINH1.1, U2.9 (IO1), U3.1 (32KHZ)
DN: D1.4 (I/O2_2), J2.A7, J2.B7
DP: D1.6 (I/O1_2), J2.A6, J2.B6
EPD_3V3: C7.1, EPD_C5.1, J1.15, J1.16, L1.2, Q2.2 (S), TP17.TP
EPD_3V3_C: Q2.1 (G), R_CL1.2, TP13.TP, U2.18 (IO20)
EPD_BUSY: J1.9, TP9.TP, U2.26 (IO3)
EPD_CS: D6.1, J1.12, R9.1, TP10.TP, U2.11 (IO10)
EPD_DC: J1.11, TP11.TP, U2.5 (IO5)
EPD_RST: J1.10, TP12.TP, U2.21 (IO23)
FLASH_CS: D9.1, R5.1, U1.1 (!CS), U2.12 (IO11)
GDR: J1.2, Q3.1 (G), R4.1
GND: BOOT_BUTTON.1, BOOT_BUTTON.2, C1.2, C1_BAT.2, C1_BAT1.2, C1_BAT2.2, C2.2, C2_BAT.2, C3.-, C4_USB.2, C5.2, C5_USB.2, C6.2, C7.2, C8.2, C9.2, C10.2, C10_SUPERCAP.1, CHANGE_BUTTON.1, CHANGE_BUTTON.2, C_DELAY.2, D1.2 (GND), D3.1 (K), D6.2, D8.2, D9.2, D10.2, D11.2, D12.2, EPD_C1.2, EPD_C2.2, EPD_C5.2, EPD_C6.2, EPD_C7.2, EPD_C8.2, EPD_C9.2, EPD_C10.2, EPD_C11.2, EPD_C12.2, IC1.3 (GND), IC4.2 (VSS), J1.8, J1.17, J1.MP1, J1.MP2, J2.A1, J2.A12, J2.B1, J2.B12, J2.MP1, J2.MP2, J2.MP3, J2.MP4, J3.1, J4.G1 (GND_1), J4.G2 (GND_2), J4.G3 (GND_3), J4.G4 (GND_4), J4.P6 (VSS), R1_PWRUSB.1, R2.1, R2-USB.2, R2-USB1.1, R2_BAT.1, R4.2, RESET_BUTTON.1, RESET_BUTTON.2, SENSOR2.1 (GND), SENSOR2.5 (SDO), SENSOR2.7 (GND), SJ1.1, TP4.TP, TP5.TP, U1.4 (GND), U1.9 (EXP), U2.1 (GND), U2.28 (GND), U2.29_1 (GND), U2.29_2 (GND), U2.29_3 (GND), U2.29_4 (GND), U2.29_5 (GND), U2.29_6 (GND), U2.29_7 (GND), U2.29_8 (GND), U2.29_9 (GND), U3.13 (GND), U4.1 (CTG), U4.4 (GND), U4.6 (QSTRT), U4.9 (EP), U5.2 (VSS)
GPIO8: R1.2, U2.10 (IO8)
I2C_PW: C1.1, C2.1, R1_PINH.2, R2_PINH.2, SENSOR2.2 (CSB), SENSOR2.6 (VDDIO), SENSOR2.8 (VDD), U2.17 (IO19)
INT_RTC: R1_PINH1.1, TP15.TP, U2.8 (IO0), U3.3 (SQW/!INT)
IO/BOOT: BOOT_BUTTON.3, BOOT_BUTTON.4, C6.1, R_BOOT.2, U2.15 (IO9)
IO/CHANGE: C10.1, CHANGE_BUTTON.3, CHANGE_BUTTON.4, R_CHANGE.2, U2.23 (IO15)
MISO: D12.1, J4.P7 (DAT0), R8.1, TP6.TP, U1.2 (DO(IO1)), U2.27 (IO2)
MOSI: D11.1, J1.14, J4.P3 (CMD), R7.1, TP7.TP, U1.5 (DI(IO0)), U2.7 (IO7)
unnamed: EPD_C2.1, J1.5
unnamed: D7.1 (CATHODE), R_CAPACITOR.2
unnamed: C_DELAY.1, IC1.5 (CT)
unnamed: EPD_C1.1, J1.4
unnamed: EPD_C6.1, J1.18
unnamed: EPD_C7.1, J1.19
unnamed: EPD_C8.1, J1.20
unnamed: C4.1, D3.2 (A), D4.1 (K)
unnamed: EPD_C10.1, J1.22
unnamed: R2_BAT.2, U5.5 (PROG)
unnamed: EPD_C12.1, J1.24
unnamed: R1_BAT.1, U5.1 (STAT)
unnamed: CHG_LED.C, R1_BAT.2
unnamed: C1_BAT1.1, D2.1 (CATHODE), IC4.1 (VIN), IC4.3 (CE), Q1.2 (S)
unnamed: J2.B5, R2-USB.1
unnamed: J2.A5, R2-USB1.2
PREVGH: D5.1 (K), EPD_C9.1, J1.21
PREVGL: D4.2 (A), EPD_C11.1, J1.23
RESE: J1.3, Q3.2 (S), R3.1
RESE': R2.2, R3.2, SJ1.2
RESET: C5.1, IC1.1 (VOUT), RESET_BUTTON.3, RESET_BUTTON.4, R_RESET.2, U2.3 (EN)
RTC_RST: U2.16 (IO18), U3.4 (!RST)
RX: TP2.TP, U2.24 (RXD0/GPIO17)
SCK: D10.1, J1.13, J4.P5 (CLK), R6.1, TP8.TP, U1.6 (CLK), U2.6 (IO6)
SCL: J3.4, R2_PINH.1, SENSOR2.4 (SCK), U2.20 (IO22), U3.16 (SCL), U4.7 (SCL)
SDA: J3.3, R1_PINH.1, SENSOR2.3 (SDI), U2.19 (IO21), U3.15 (SDA), U4.8 (SDA)
SRC: C4.2, D5.2 (A), L1.1, Q3.3 (D)
SS_SD: D8.1, J4.P2 (CD/DAT3), R10.1, U2.4 (IO4)
TX: TP1.TP, U2.25 (TXD0/GPIO16)
USB_D+: D1.1 (I/O1_1), U2.14 (IO13)
USB_D-: D1.3 (I/O2_1), U2.13 (IO12)
VBAT: C2_BAT.1, Q1.3 (D), TP3.TP, U4.2 (CELL), U4.3 (VDD), U5.3 (VBAT)
VBUS: C1_BAT.1, C4_USB.1, C5_USB.1, CHG_LED.A, D1.5 (VBUS), D2.2 (ANODE), PFMF.050.1.2, Q1.1 (G), R1_PWRUSB.2, TP14.TP, U5.4 (VIN)
VRTC: C8.1, C10_SUPERCAP.2, R_CAPACITOR.1, U3.14 (VBAT)
VUSB: J2.A4, J2.A9, J2.B4, J2.B9, PFMF.050.1.1

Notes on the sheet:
SD Card
ESP32 C6
Battery Charge Level
External NOR Flash 64MB
SPI ESD Protection Lines
Qwiic / Stemma QT
Test Pads
RTC Module DS3231SN
Voltage Supervisor + Reset & Boot / IO Button
Environmental Sensor BME688
EPD Power
E-Paper Display Header
Display Type Selector
E-Paper Drive Circuit
Li-Po Battery Charging Controller
LDO Voltage Regulator
USB C connector & ESD protection

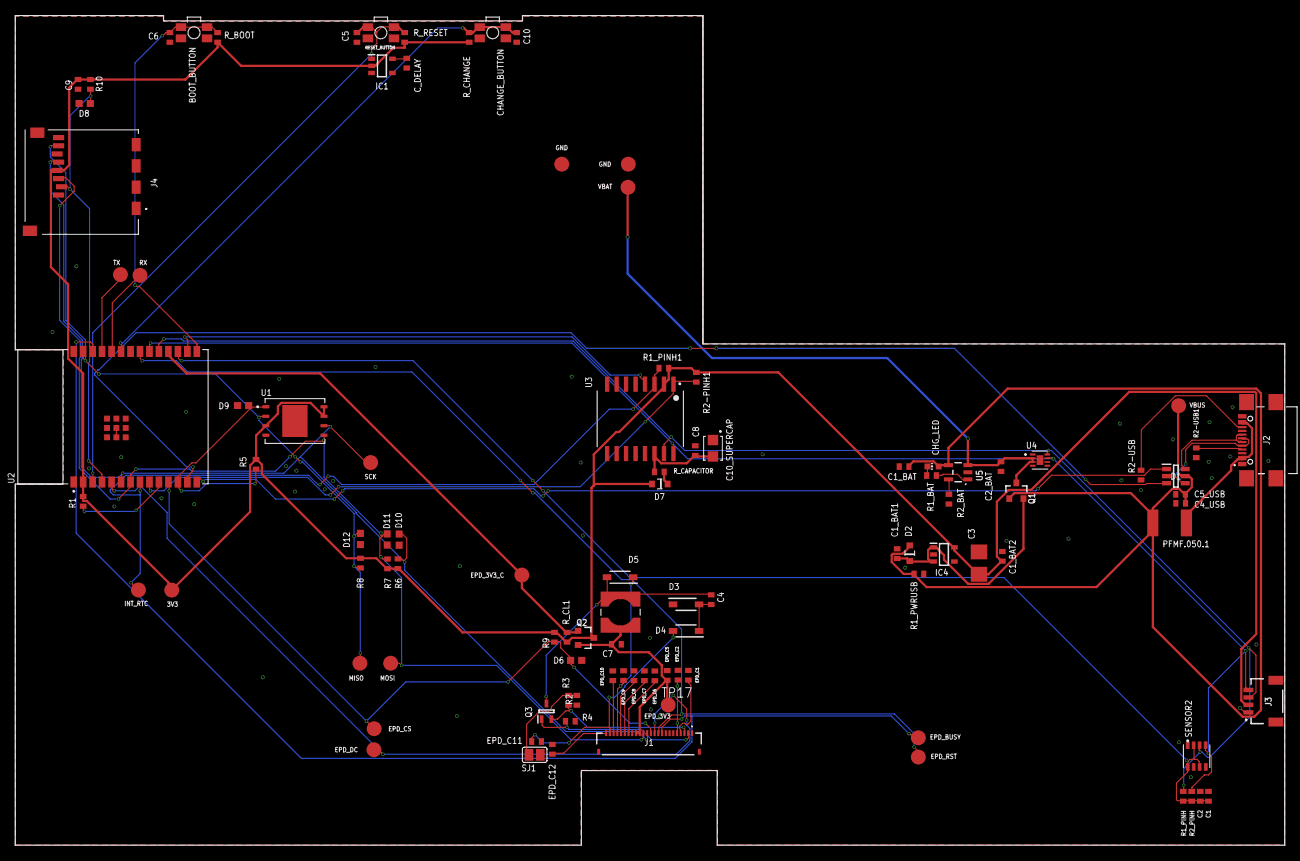
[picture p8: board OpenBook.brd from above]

Board: 2 copper layers, 170.2 x 111.2 mm, 103 parts (0 on the bottom side), 55 nets.

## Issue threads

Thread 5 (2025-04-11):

PCB - "Goluri" in planul de masa

catalin-giuglan, 2025-04-11:
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
Atasez link la mesajul de pe teams in care explica profesorul cum sa rezolvi asta.
https://teams.microsoft.com/l/message/19:de41UIg-Kw9l2gSJREYXzCUl0TyWzT9KYZOCbGyNKgA1@thread.tacv2/1743919251795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

Closed 2025-04-11.

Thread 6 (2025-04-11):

PCB - Lipsa Custom Rules

catalin-giuglan, 2025-04-11:
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
Ai putea sa adaugi custom rules la copper width pentru a te asigura ca ai cablurile de dimensiuea corespunzatoare.

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
Aici poti adauga 2 net class-uri noi, una pentru trasee de alimentare si una pentru celelalte.

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
Aici poti seta dimensiunea din cerinta si sa selectezi netclass-ul dorit.

Closed 2025-04-11.

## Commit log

2025-03-30 Add manufacturing files
    [OpenBook.csv, PnP_OpenBook_back.csv, PnP_OpenBook_front.csv]
2025-03-30 Added gerbers to manufacturing folder
2025-03-30 Add renders of the components and the full device
2025-04-04 Finished the entire design
    [OpenBook.brd, OpenBook.sch]
2025-04-04 Reuploaded all files
    [OpenBook.brd, OpenBook.csv, OpenBook.sch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]
2025-04-11 Solved some issues related to the 2d PCB
    [OpenBook.brd, OpenBook.sch]

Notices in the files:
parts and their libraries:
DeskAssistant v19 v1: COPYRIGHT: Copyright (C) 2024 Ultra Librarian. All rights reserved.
